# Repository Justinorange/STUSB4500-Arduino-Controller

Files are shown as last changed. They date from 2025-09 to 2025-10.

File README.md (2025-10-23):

# STUSB4500 USB-C Power Delivery (PD) Sink Controller

A custom **KiCAD project** for building a **USB Power Delivery (USB-PD) Sink Board** utilizing the STMicroelectronics **STUSB4500** controller.

This board provides a powerful and flexible way to draw high-power **variable voltage** from any standard USB-C PD power source. It is designed to be fully controllable by an external host microcontroller, via the **I²C bus**.

---

## Features

* **USB-PD Protocol Negotiation**: Automatically handles the USB-PD handshake process.
* **I²C Control**: Allows a host MCU (e.g., Arduino, ESP32) to digitally request specific voltages.
* **Configurable Voltages**: Supports requesting standard USB-PD voltages: **5V, 9V, 12V, 15V, or 20V**.
* **Compact Design**: Designed as a simple, custom PCB project in KiCAD.

---

## Hardware Overview

The board is designed around the dedicated **STUSB4500** chip, which simplifies the PD sink implementation significantly by handling the communication protocol stack internally.

| Component | Description |
| :--- | :--- |
| **Controller IC** | STUSB4500 USB-PD Sink Controller |
| **Input** | USB-C receptacle for PD power source input |
| **Host Interface** | 5-pin JST connector for I²C communication with the microcontroller |
| **Power Output** | 2-pin JST connector for regulated DC output power |

The full schematic and PCB layout files are available in the KiCAD project directory (`/kicad/`).

---

## I²C Connection Pinout

This pinout is designed for compatibility with the ESP32 Arduino Nano, using a standard **5-pin JST header**.

| STUSB4500 Board Pin | Signal | Arduino (e.g., Nano/Uno) | Function |
| :--- | :--- | :--- | :--- |
| **SDA** | I²C Data | A4 | I²C Serial Data Line |
| **SCL** | I²C Clock | A5 | I²C Serial Clock Line |
| **RST** | Reset | D0 | External Reset Pin for STUSB4500 |
| **VDD** | Power Input | Vin (20V) | Power Supply for Arduino/STUSB4500 Logic |
| **GND** | Ground | GND | Common Ground Reference |

---

## How to Use (Arduino Example)

Follow these steps to quickly test and control the power negotiation using an Arduino or compatible microcontroller.

### Prerequisites

* **Code**: You will need the specific library/code to communicate with the STUSB4500 over I²C.
* **Connection**: Ensure the board is wired correctly according to the table above.
* **Power**: Connect a **USB-C PD power source** (charger) to the board's USB-C input.

### Negotiation Workflow

1.  **Upload**: Upload the I²C configuration code to your Arduino.
2.  **Monitor**: Open the **Serial Monitor** at 9600 baud.
3.  **Input**: Enter the desired target voltage (**5, 9, 12, 15, or 20**) and press Enter.
4.  **Negotiation**: The Arduino code will:
    * Configure the STUSB4500's I²C registers with the requested voltage.
    * The **STUSB4500 chip** will initiate a negotiation request to the power source.
5.  **Status**: The negotiated status (Success or Failure) and the resulting stable output voltage will be printed back to the Serial Monitor.
6.  **Output**: The requested voltage will be delivered to the **2-pin JST output terminal**.

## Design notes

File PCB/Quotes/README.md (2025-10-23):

# Pricing and Sourcing

---

## Lowest PCB Price

The lowest price for **PCB fabrication** was provided by **OSH Park**.

* *Note:* A potential way to get a lower price is by ordering from a manufacturer in China.

---

## Bill of Materials (BOM)

A complete **Bill of Materials (BOM)** is available, detailing all necessary components and their prices.

* All components can be sourced from **Digi-Key**.
* **[View the Bill of Materials (BOM)](BOM-STUSB.xlsx)**

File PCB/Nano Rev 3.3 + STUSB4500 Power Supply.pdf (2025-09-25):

# Nano Rev 3.3 + STUSB4500 Power Supply

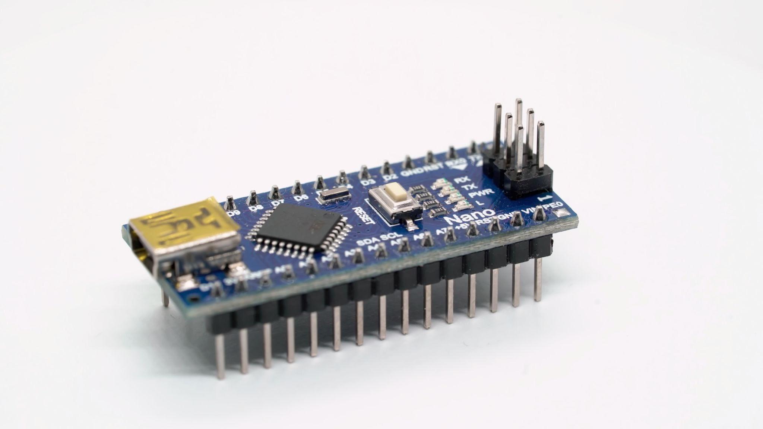
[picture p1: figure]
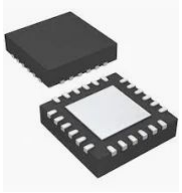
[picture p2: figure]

# USB Interface

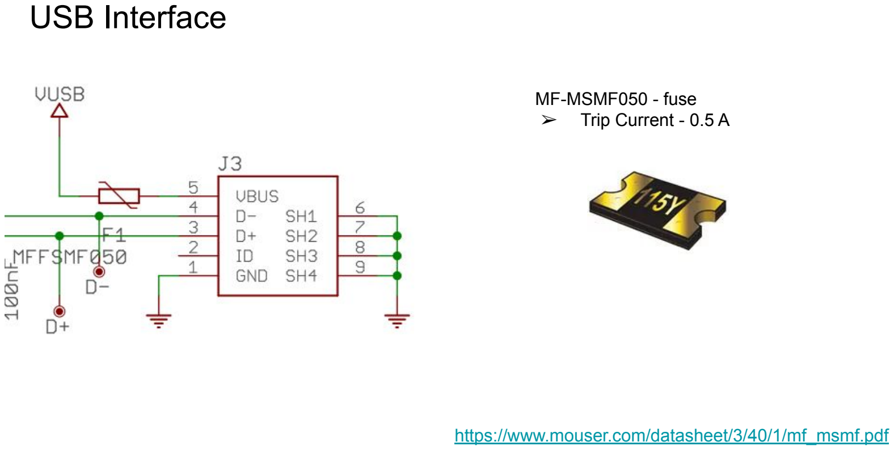
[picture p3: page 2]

MF-MSMF050 - fuse
- Trip Current - 0.5 A

https://www.mouser.com/datasheet/3/40/1/mf_msmf.pdf

# VUSB to 5V

SS1P3L - Diode
- Reverse Amps - 200 μA

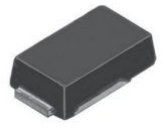
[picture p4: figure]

Reverse Peak Voltage - 30 V

https://www.vishay.com/docs/88915/ss1p3l.pdf

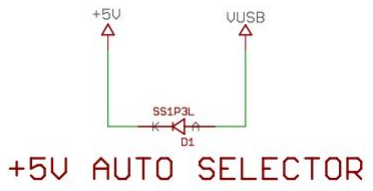
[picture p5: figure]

# VIN to 5V

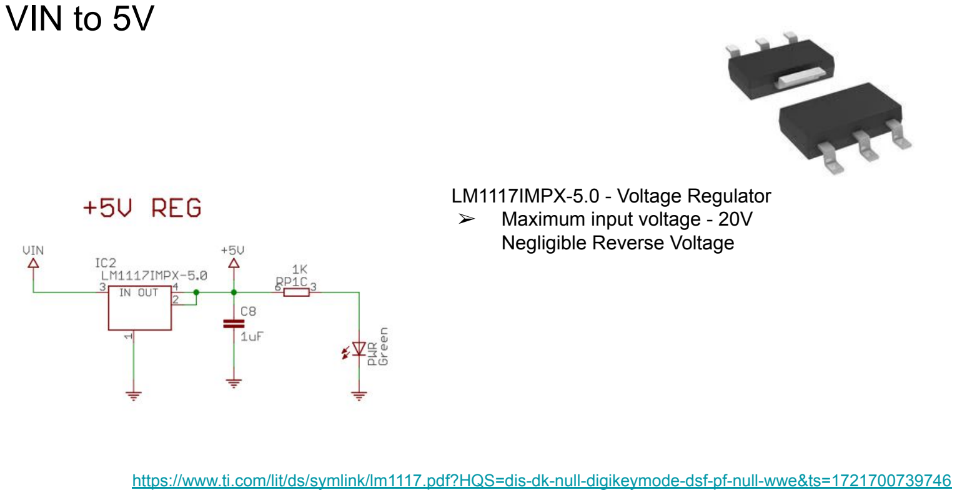
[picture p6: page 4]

LM1117IMPX-5.0 - Voltage Regulator
- Maximum input voltage - 20V Negligible Reverse Voltage

https://www.ti.com/lit/ds/symlink/lm1117.pdf?HQS=dis-dk-null-digikeymode-dsf-pf-null-wwe&ts=1721700739746

# 5V to Arduino IC

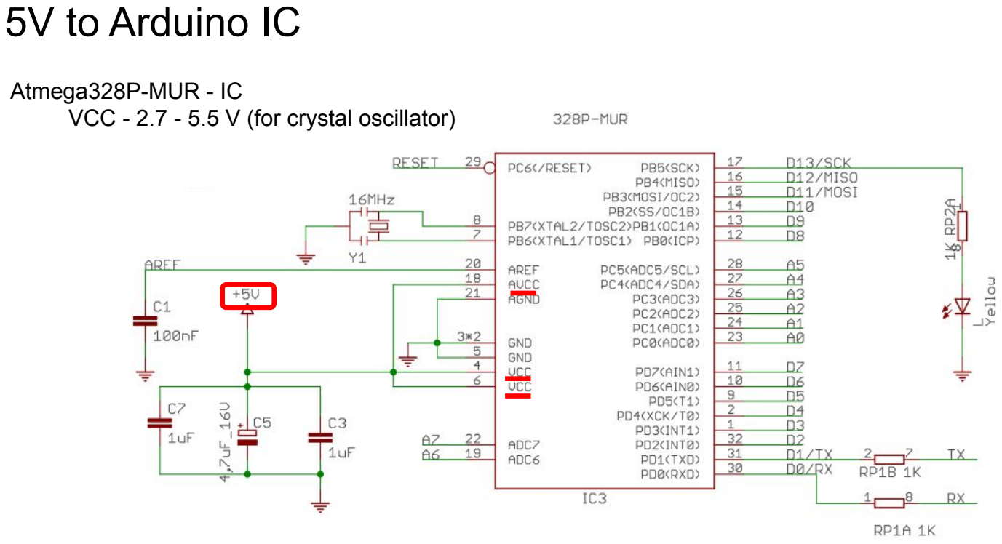
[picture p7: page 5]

Atmega328P-MUR - IC
VCC - 2.7 - 5.5 V (for crystal oscillator)

# 3V3 & FT23RL

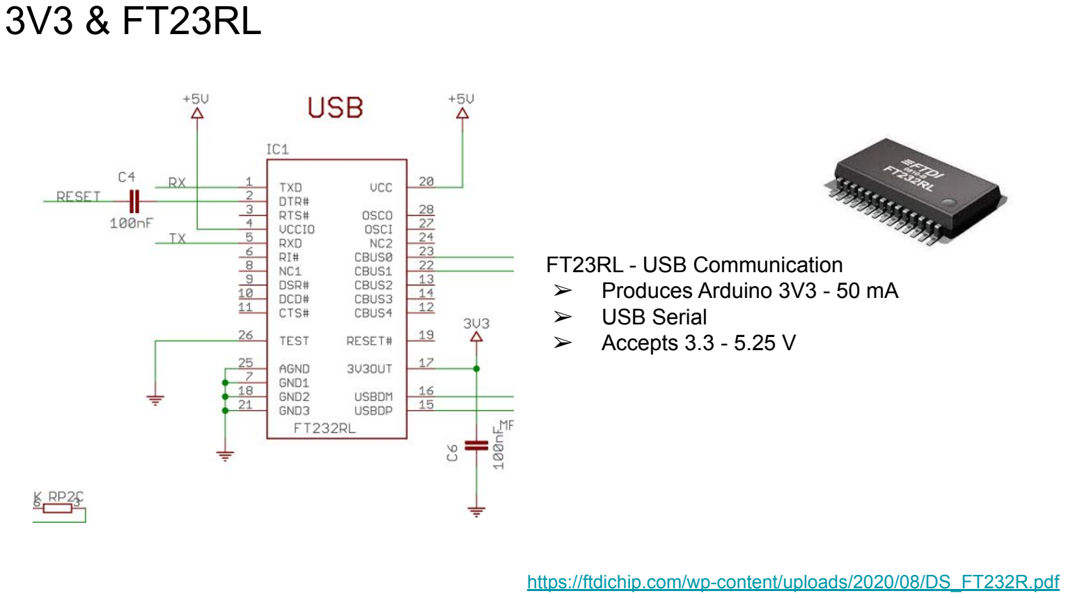
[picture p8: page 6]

FT23RL - USB Communication
- Produces Arduino 3V3 - 50 mA
- USB Serial
- Accepts 3.3 - 5.25 V

https://ftdichip.com/wp-content/uploads/2020/08/DS_FT232R.pdf

# Power Movement

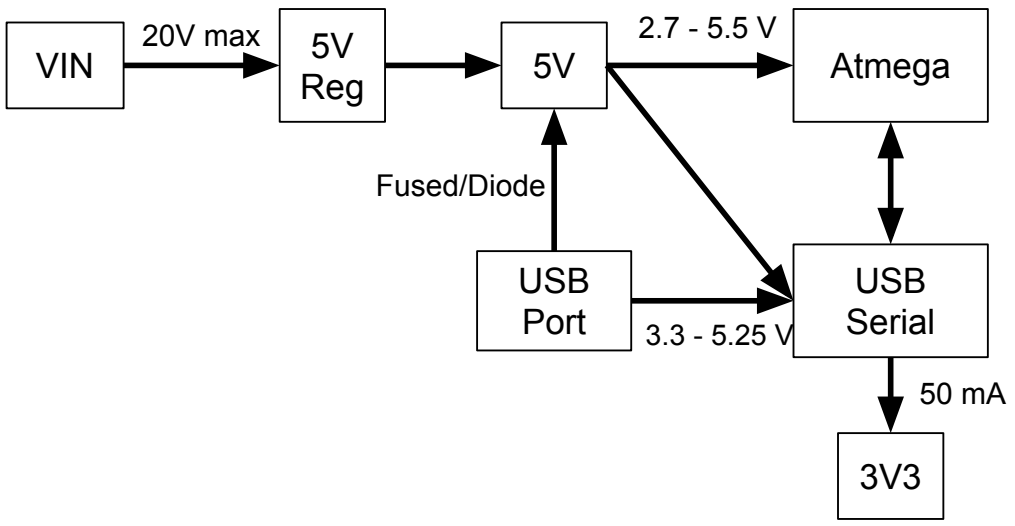
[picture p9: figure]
VIN; Reg; Atmega; USB Serial; USB Port; 20V max; Fused/Diode

# Schematic

## https://docs.arduino.cc/resources/schematics/A000005-schematics.pdf

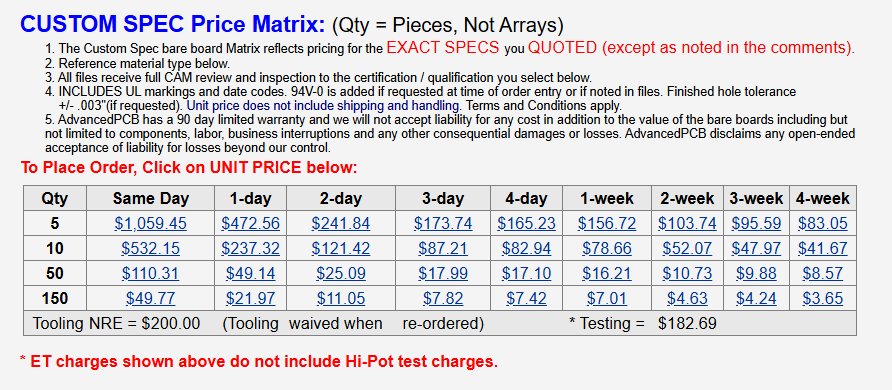
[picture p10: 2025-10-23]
PCB/Quotes/AdvancedPCB.png

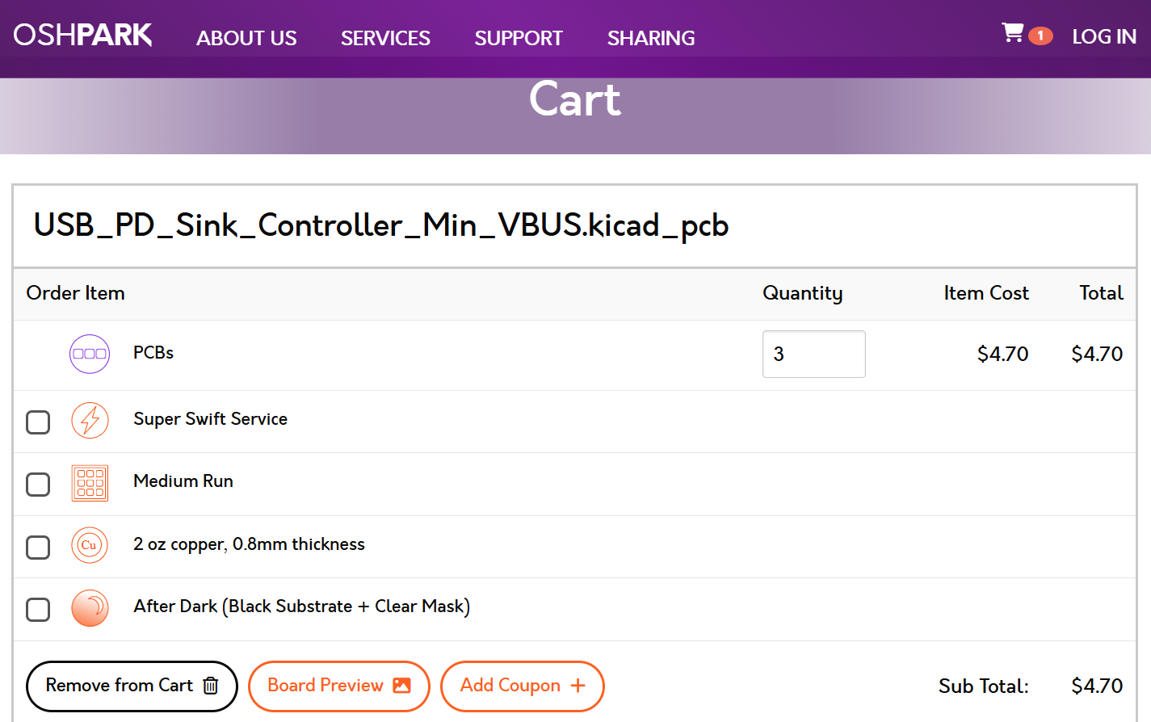
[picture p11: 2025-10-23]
PCB/Quotes/OSHPark.png

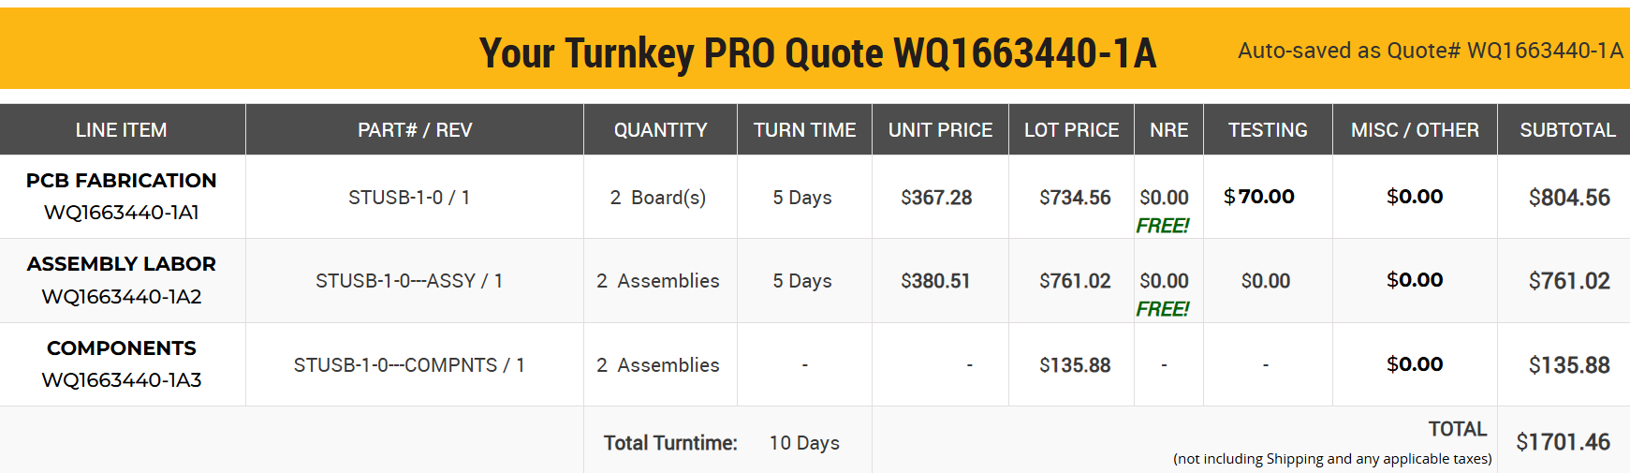
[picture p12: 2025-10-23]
PCB/Quotes/SierraQuote.png

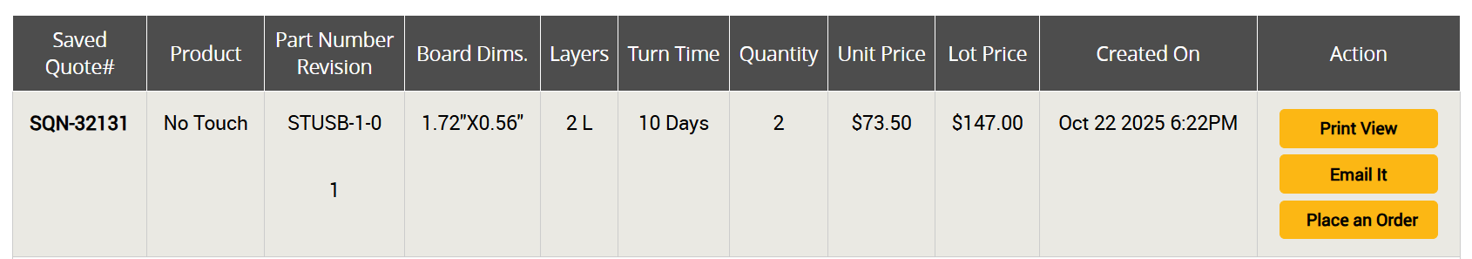
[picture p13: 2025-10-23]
PCB/Quotes/CheaperSierraCircuits.png

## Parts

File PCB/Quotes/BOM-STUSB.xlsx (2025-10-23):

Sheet: Sierra Sample BOM
BOM: STUSB-1-0
Assembly Part Number/Revision: 1
Item # | Quantity per board | Manufacturer Part # | Unit Price | Reference designators | Value (optional) | Total Price
2 | 1 | TMK107BBJ475KA-T | $0.28 | C1 | 4.7 μF | $0.28
3 | 4 | UMK107BJ105KA-T | $0.08 | C2,C3,C4,C5 | 1μF | $0.32
4 | 1 | TMK107BJ104KA-T | $0.08 | C6 | 100nF | $0.08
5 | 2 | ESDA25P35-1U1M | $0.37 | D1,D4 | ESDA25P35-1U1M | $0.74
6 | 1 | ESDA25W | $0.42 | D2 | ESDA25W | $0.42
7 | 2 | CD0603-B0240R | $0.21 | D3,D5 | Diode | $0.42
8 | 1 | USB4105-GF-A | $0.78 | J1 | USB_C_Receptacle_PowerOnly_6P | $0.78
9 | 1 | S2B-XH-A | $0.12 | J2 | JST_01x02_Socket | $0.12
10 | 1 | S5B-XH-A | $0.22 | J3 | JST_01x05_Socket | $0.22
11 | 1 | RC0603JR-07470RL | $0.10 | R1 | 470R | $0.10
12 | 2 | RT0603FRE071KL | $0.10 | R2,R6 | 1kR | $0.20
13 | 1 | RT0603DRE0722KL | $0.10 | R3 | 22kR | $0.10
14 | 1 | RC0603FR-07100KL | $0.10 | R4 | 100kR | $0.10
15 | 1 | RT0603DRE07100RL | $0.10 | R5 | 100R | $0.10
16 | 1 | CRCW080510K0FKEA | $0.10 | R7 | 10kR | $0.10
17 | 2 | RC0603JR-074K7L | $0.10 | R8,R10 | 4.7kR | $0.20
18 | 1 | STUSB4500QTR | $1.96 | U1 | STUSB4500QTR | $1.96
19 | 2 | STL6P3LLH6 | $1.54 | U2,U3 | STL6P3LLH6 | $3.08
Total | $9.32
END OF BOM

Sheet: USB_PD_Sink_Controller_Min_VBUS
Reference | Qty | Value | DNP | Exclude from BOM | Exclude from Board | Footprint | Datasheet
A1 | 1 | Arduino_Nano_ESP32 |  |  |  | Module:Arduino_Nano | https://docs.arduino.cc/resources/datasheets/ABX00083-datasheet.pdf
C1 | 1 | 4.7 μF |  |  |  | Capacitor_SMD:C_0603_1608Metric_Pad1.08x0.95mm_HandSolder | ~
C2,C3,C4,C5 | 4 | 1μF |  |  |  | Capacitor_SMD:C_0603_1608Metric_Pad1.08x0.95mm_HandSolder | ~
C6 | 1 | 100nF |  |  |  | Capacitor_SMD:C_0603_1608Metric_Pad1.08x0.95mm_HandSolder | ~
D1,D4 | 2 | ESDA25P35-1U1M |  |  |  | ST_1610:ST_1610 | kicad-embed://esda25p35-1u1m.pdf
D2 | 1 | ESDA25W |  |  |  | ST_SOT323-3L:ST_SOT323-3L
D3,D5 | 2 | D |  |  |  | Diode_SMD:D_0603_1608Metric_Pad1.05x0.95mm_HandSolder | ~
J1 | 1 | USB_C_Receptacle_PowerOnly_6P |  |  |  | Connector_USB:USB_C_Receptacle_GCT_USB4105-xx-A_16P_TopMnt_Horizontal | https://www.usb.org/sites/default/files/documents/usb_type-c.zip
J2 | 1 | JST_01x02_Socket |  |  |  | Connector_JST:JST_XH_S2B-XH-A_1x02_P2.50mm_Horizontal | ~
J3 | 1 | JST_01x05_Socket |  |  |  | Connector_JST:JST_XH_S5B-XH-A_1x05_P2.50mm_Horizontal | ~
R1 | 1 | 470R |  |  |  | Resistor_SMD:R_0603_1608Metric_Pad0.98x0.95mm_HandSolder | ~
R2,R6 | 2 | 1kR |  |  |  | Resistor_SMD:R_0603_1608Metric_Pad0.98x0.95mm_HandSolder | ~
R3 | 1 | 22kR |  |  |  | Resistor_SMD:R_0603_1608Metric_Pad0.98x0.95mm_HandSolder | ~
R4 | 1 | 100kR |  |  |  | Resistor_SMD:R_0603_1608Metric_Pad0.98x0.95mm_HandSolder | ~
R5 | 1 | 100R |  |  |  | Resistor_SMD:R_0603_1608Metric_Pad0.98x0.95mm_HandSolder | ~
R7 | 1 | 10kR |  |  |  | Resistor_SMD:R_0603_1608Metric_Pad0.98x0.95mm_HandSolder | ~
R8,R10 | 2 | 4.7kR |  |  |  | Resistor_SMD:R_0603_1608Metric_Pad0.98x0.95mm_HandSolder | ~
U1 | 1 | STUSB4500QTR |  |  |  | Package_DFN_QFN:QFN-24-1EP_4x4mm_P0.5mm_EP2.7x2.7mm | https://www.st.com/resource/en/datasheet/stusb4500.pdf
U2,U3 | 2 | STL6P3LLH6 |  |  |  | STL6P3LLH6:POWERFLAT_3P3X3P3_STM2 | https://www.st.com/resource/en/datasheet/stl6p3llh6.pdf

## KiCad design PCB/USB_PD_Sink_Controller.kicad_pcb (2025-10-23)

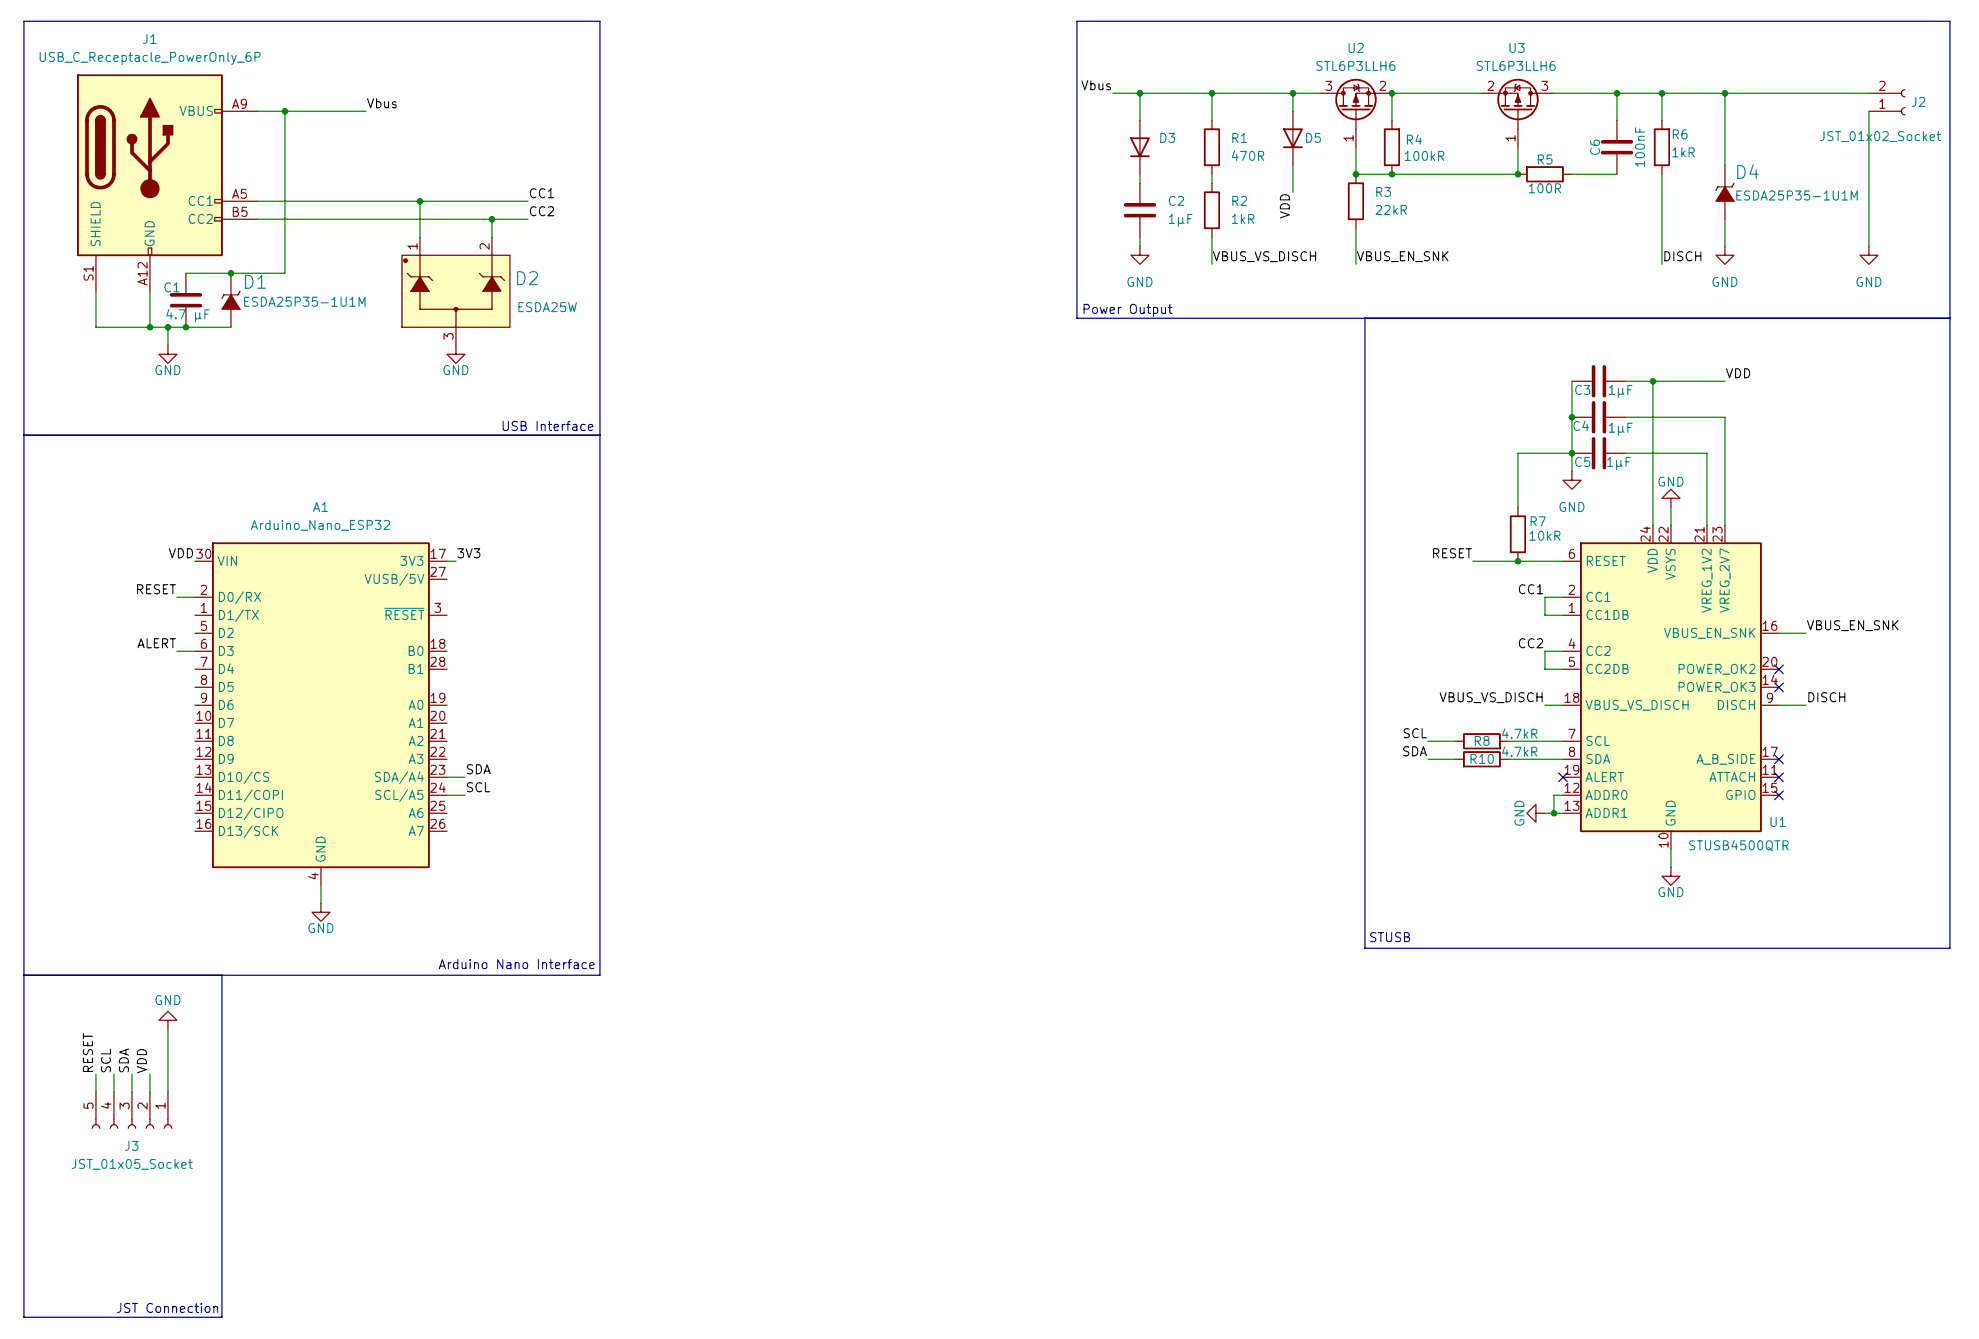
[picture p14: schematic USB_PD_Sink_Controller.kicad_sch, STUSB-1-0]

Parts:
A1: Arduino_Nano_ESP32; Arduino_Nano
C1: 4.7 μF; C_0603_1608Metric_Pad1.08x0.95mm_HandSolder
C2, C3, C4, C5: 1μF; C_0603_1608Metric_Pad1.08x0.95mm_HandSolder
C6: 100nF; C_0603_1608Metric_Pad1.08x0.95mm_HandSolder
D1, D4: ESDA25P35-1U1M; ST_1610
D2: ESDA25W; ST_SOT323-3L
D3, D5: D; D_0603_1608Metric_Pad1.05x0.95mm_HandSolder
J1: USB_C_Receptacle_PowerOnly_6P; USB_C_Receptacle_GCT_USB4105-xx-A_16P_TopMnt_Horizontal
J2: JST_01x02_Socket; JST_XH_S2B-XH-A_1x02_P2.50mm_Horizontal
J3: JST_01x05_Socket; JST_XH_S5B-XH-A_1x05_P2.50mm_Horizontal
R1: 470R; R_0603_1608Metric_Pad0.98x0.95mm_HandSolder
R2, R6: 1kR; R_0603_1608Metric_Pad0.98x0.95mm_HandSolder
R3: 22kR; R_0603_1608Metric_Pad0.98x0.95mm_HandSolder
R4: 100kR; R_0603_1608Metric_Pad0.98x0.95mm_HandSolder
R5: 100R; R_0603_1608Metric_Pad0.98x0.95mm_HandSolder
R7: 10kR; R_0603_1608Metric_Pad0.98x0.95mm_HandSolder
R8, R10: 4.7kR; R_0603_1608Metric_Pad0.98x0.95mm_HandSolder
U1: STUSB4500QTR; QFN-24-1EP_4x4mm_P0.5mm_EP2.7x2.7mm
U2, U3: STL6P3LLH6; POWERFLAT_3P3X3P3_STM2

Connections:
/CC1: D2.1, J1.A5 (CC1), U1.1 (CC1DB), U1.2 (CC1)
/CC2: D2.2, J1.B5 (CC2), U1.4 (CC2), U1.5 (CC2DB)
/DISCH: R6.1, U1.9 (DISCH)
/RESET: A1.2 (D0/RX), J3.5, R7.2, U1.6 (RESET)
/SCL: A1.24 (SCL/A5), J3.4, R8.1
/SDA: A1.23 (SDA/A4), J3.3, R10.2
/VBUS_EN_SNK: R3.2, U1.16 (VBUS_EN_SNK)
/VBUS_VS_DISCH: R2.2, U1.18 (VBUS_VS_DISCH)
/VDD: A1.30 (VIN), C3.1, D5.1 (K), J3.2, U1.24 (VDD)
/Vbus: C1.1, D1.1 (K), D3.2 (A), D5.2 (A), J1.A9 (VBUS), J1.B9 (VBUS), R1.1, U2.3 (D)
GND: A1.4 (GND), A1.29 (GND), C1.2, C2.2, C3.2, C4.2, C5.2, D1.2 (A), D2.3, D4.2 (A), J1.A12 (GND), J1.B12 (GND), J1.S1 (SHIELD), J2.1, J3.1, R7.1, U1.10 (GND), U1.12 (ADDR0), U1.13 (ADDR1), U1.22 (VSYS), U1.25 (GND)
unnamed: C6.1, R5.1
unnamed: C2.1, D3.1 (K)
unnamed: C6.2, D4.1 (K), J2.2, R6.2, U3.3 (D)
unnamed: R1.2, R2.1
unnamed: R8.2, U1.7 (SCL)
unnamed: R10.1, U1.8 (SDA)
unnamed: C5.1, U1.21 (VREG_1V2)
unnamed: C4.1, U1.23 (VREG_2V7)
unnamed: R3.1, R4.1, R5.2, U2.1 (G), U3.1 (G)
unnamed: R4.2, U2.2 (S), U3.2 (S)

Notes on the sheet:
STUSB
Arduino Nano Interface
JST Connection
USB Interface
Power Output

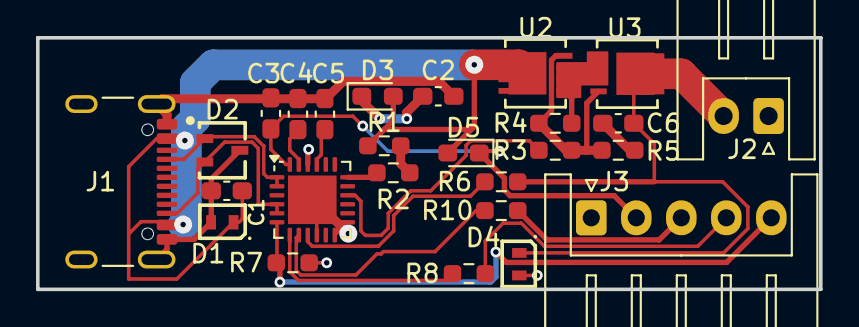
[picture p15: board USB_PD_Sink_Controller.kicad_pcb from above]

Board: 2 copper layers, 43.5 x 14.0 mm, 26 parts (0 on the bottom side), 21 nets.

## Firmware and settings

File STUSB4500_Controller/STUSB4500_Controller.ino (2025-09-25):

/*
  STUSB4500 USB PD Voltage Controller for Arduino Nano

  This sketch communicates with the STUSB4500 USB PD controller chip
  over I2C to change the negotiated power profile (voltage).

  Hardware Setup:
  - Arduino Nano
  - STUSB4500 Breakout Board
  - Arduino A4 (SDA) -> STUSB4500 SDA
  - Arduino A5 (SCL) -> STUSB4500 SCL
  - Arduino D2 -> STUSB4500 ALERT
  - Arduino GND -> STUSB4500 GND
  - Arduino 5V -> STUSB4500 VDD (if not powered from VBUS)
  - Ensure necessary pull-up resistors are in place for I2C lines and ALERT.

  How to Use:
  1. Upload this code to your Arduino Nano.
  2. Open the Serial Monitor (baud rate: 9600).
  3. Type one of the following commands and press Enter:
     - '5' to request 5V
     - '9' to request 9V
     - '12' to request 12V
     - '15' to request 15V
     - '20' to request 20V
  4. The STUSB4500 will then negotiate the requested voltage with the USB PD source.
  5. The ALERT pin will signal when a new negotiation is complete or if an event occurs.
*/

#include <Wire.h>

// I2C address of the STUSB4500. Default is 0x28.
// Can be 0x29, 0x2A, or 0x2B depending on ADDR0 and ADDR1 pins.
#define STUSB4500_ADDRESS 0x28

// STUSB4500 Register Addresses
#define PDO_NUM_REG 0x70
#define V_SNK_PDO2_REG 0x85
#define V_SNK_PDO3_REG 0x87

// Digital pin connected to the STUSB4500's ALERT pin
#define ALERT_PIN 2

// A volatile boolean flag to be used by the interrupt service routine
volatile bool alert_flag = false;

void setup() {
  // Initialize Serial communication at 9600 baud
  Serial.begin(9600);
  Serial.println("STUSB4500 Voltage Controller Initialized");
  Serial.println("Enter a voltage (5, 9, 12, 15, or 20) to request a new power profile.");

  // Initialize I2C communication
  Wire.begin();

  // Set the ALERT pin as an input with a pull-up resistor
  pinMode(ALERT_PIN, INPUT_PULLUP);
  // Attach an interrupt to the ALERT pin, to be triggered on a falling edge
  attachInterrupt(digitalPinToInterrupt(ALERT_PIN), handleAlert, FALLING);
  
  // Initial soft reset of the STUSB4500 NVM to load default settings
  // This helps ensure the chip is in a known state.
  // Note: For production use, you would pre-program the NVM.
  // This example dynamically changes PDOs in RAM.
  i2cWrite(0x25, 0x01); // Trigger NVM read
  delay(10); // Wait for NVM to load
}

void loop() {
  // Check if there is data available to read from the serial port
  if (Serial.available() > 0) {
    // Read the incoming integer
    int target_voltage = Serial.parseInt();

    // Process the command
    switch (target_voltage) {
      case 5:
        Serial.println("Requesting 5V...");
        setVoltage(5);
        break;
      case 9:
        Serial.println("Requesting 9V...");
        setVoltage(9);
        break;
      case 12:
        Serial.println("Requesting 12V...");
        setVoltage(12);
        break;
      case 15:
        Serial.println("Requesting 15V...");
        setVoltage(15);
        break;
      case 20:
        Serial.println("Requesting 20V...");
        setVoltage(20);
        break;
      default:
        Serial.println("Invalid voltage. Please enter 5, 9, 12, 15, or 20.");
        break;
    }
  }

  // If the alert flag was set by the ISR, print a message and reset it
  if (alert_flag) {
    // An alert can be for various reasons. We check the negotiated power data object (PDO)
    // to see if the voltage contract has changed.
    uint8_t pdo_index = i2cRead(RDO_REG_STATUS) & 0x0F; // Read Sink PDO number in use

    int new_voltage = 0;

    switch (pdo_index) {
      case 1: // PDO1 is always 5V
        new_voltage = 5;
        break;
      case 2: // PDO2
        {
          // Read the 10-bit value from the register
          uint16_t pdo2_val = i2cRead(V_SNK_PDO2_REG) | ((i2cRead(V_SNK_PDO2_REG + 1) & 0x03) << 8);
          // Convert to volts (value * 50mV)
          new_voltage = (int)((pdo2_val * 50L) / 1000L);
        }
        break;
      case 3: // PDO3
        {
          // Read the 10-bit value from the register
          uint16_t pdo3_val = i2cRead(V_SNK_PDO3_REG) | ((i2cRead(V_SNK_PDO3_REG + 1) & 0x03) << 8);
          // Convert to volts (value * 50mV)
          new_voltage = (int)((pdo3_val * 50L) / 1000L);
        }
        break;
    }

    if (new_voltage != 0 && new_voltage != currentNegotiatedVoltage) {
      currentNegotiatedVoltage = new_voltage;
      Serial.print("Negotiation successful. Voltage is now: ");
      Serial.print(currentNegotiatedVoltage);
      Serial.println("V");
    } else {
      Serial.println("Alert received from STUSB4500 (no voltage change or status update).");
    }

    alert_flag = false;
  }
}

// Function to set the desired voltage by configuring the PDO profiles.
// The STUSB4500 supports up to 3 Sink PDOs.
// PDO1 is fixed at 5V. We will configure PDO2 and PDO3 to get other voltages.
void setVoltage(int voltage) {
  uint16_t pdo2_voltage = 0;
  uint16_t pdo3_voltage = 0;
  uint8_t num_pdos = 1; // Default is one PDO (5V)

  // According to the datasheet, the voltage is programmed in 50mV steps.
  // So, value = voltage / 0.05
  uint16_t voltage_val = voltage / 0.05;

  if (voltage == 5) {
    // To request 5V, we just set the number of PDOs to 1.
    // The STUSB4500 will then only negotiate the default 5V PDO.
    num_pdos = 1;
  } else {
    // For other voltages, we will set them as PDO2 and make PDO3 a copy.
    // This makes the negotiation more robust.
    num_pdos = 3;
    pdo2_voltage = voltage_val;
    pdo3_voltage = voltage_val;
  }
  
  // Write the voltage for PDO2 (registers 0x85 and 0x86)
  i2cWrite(V_SNK_PDO2_REG, pdo2_voltage & 0xFF);
  i2cWrite(V_SNK_PDO2_REG + 1, (pdo2_voltage >> 8) & 0x03);

  // Write the voltage for PDO3 (registers 0x87 and 0x88)
  i2cWrite(V_SNK_PDO3_REG, pdo3_voltage & 0xFF);
  i2cWrite(V_SNK_PDO3_REG + 1, (pdo3_voltage >> 8) & 0x03);

  // Set the number of active PDOs
  // Bits 6-7 of register 0x70 control this.
  // 0b00 or 0b01 -> 1 PDO
  // 0b10 -> 2 PDOs
  // 0b11 -> 3 PDOs
  uint8_t pdo_num_val = 0;
  if (num_pdos == 1) pdo_num_val = 0b01;
  if (num_pdos == 2) pdo_num_val = 0b10;
  if (num_pdos == 3) pdo_num_val = 0b11;
  
  uint8_t current_pdo_reg = i2cRead(PDO_NUM_REG);
  current_pdo_reg &= 0x3F; // Clear bits 6-7
  current_pdo_reg |= (pdo_num_val << 6);
  i2cWrite(PDO_NUM_REG, current_pdo_reg);
  
  // After changing PDOs, we need to trigger a new negotiation.
  // A soft reset is an effective way to do this.
  i2cWrite(0x25, 0x01); // Send soft reset command
  
  Serial.print("Configuration sent for ");
  Serial.print(voltage);
  Serial.println("V. Awaiting negotiation...");
}

// Interrupt Service Routine for the ALERT pin
void handleAlert() {
  alert_flag = true;
}

// Helper function to write a byte to an I2C device register
void i2cWrite(uint8_t reg, uint8_t data) {
  Wire.beginTransmission(STUSB4500_ADDRESS);
  Wire.write(reg);
  Wire.write(data);
  Wire.endTransmission();
}

// Helper function to read a byte from an I2C device register
uint8_t i2cRead(uint8_t reg) {
  Wire.beginTransmission(STUSB4500_ADDRESS);
  Wire.write(reg);
  Wire.endTransmission(false); // Send a restart message, keeping the connection active
  Wire.requestFrom(STUSB4500_ADDRESS, (uint8_t)1); // Request 1 byte from the specified register
  if (Wire.available()) {
    return Wire.read();
  }
  return 0;
}

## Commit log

2025-09-25 Added KiCAD Files
    [USB_PD_Sink_Controller.kicad_pcb, USB_PD_Sink_Controller.kicad_sch]
2025-09-25 Added Pullup resistors and alert pin
    [USB_PD_Sink_Controller.kicad_pcb, USB_PD_Sink_Controller.kicad_sch]
2025-09-25 Update STUSB4500_Controller.ino
    Changed code to add alert pin
2025-09-25 Added capacitor to linear voltage regulator
    [USB_PD_Sink_Controller.kicad_pcb, USB_PD_Sink_Controller.kicad_sch]
2025-09-25 Revamped the PCB design
    Made many of the traces thicker. Changed from a barrel jack to a JST connector. Made the schematic pretty. Made the Arduino Nano directly soldered onto the board. Etc.
    [USB_PD_Sink_Controller.kicad_pcb, USB_PD_Sink_Controller.kicad_sch]
2025-09-25 Update and rename USB_PD_Sink_Controller.kicad_pcb to PCB/USB_PD_Sink_Controller.kicad_pcb
    Moved File
    [USB_PD_Sink_Controller.kicad_pcb]
2025-09-25 moved PCB files
    [USB_PD_Sink_Controller.kicad_sch]
2025-09-25 Added Ground plane and started LDO addition to SCH
    [USB_PD_Sink_Controller.kicad_pcb, USB_PD_Sink_Controller.kicad_sch]
2025-09-25 Added Arduino power explanation slides
2025-10-02 Made the Arduino esp32 and added a diode to prevent reverse voltage
    [USB_PD_Sink_Controller.kicad_pcb, USB_PD_Sink_Controller.kicad_sch]
2025-10-02 changed to ESP32 Arduino
2025-10-15 Added JST to schem
    [USB_PD_Sink_Controller.kicad_sch]
2025-10-16 VDD input added
    [USB_PD_Sink_Controller.kicad_sch]
2025-10-16 Updated PCB
    [USB_PD_Sink_Controller.kicad_pcb, USB_PD_Sink_Controller.kicad_sch]
2025-10-16 added Vbus variant
    [USB_PD_Sink_Controller_VBUS.kicad_pcb, USB_PD_Sink_Controller_VBUS.kicad_sch]
2025-10-16 added variant with less IO
    [USB_PD_Sink_Controller_Min_VBUS.kicad_pcb, USB_PD_Sink_Controller_Min_VBUS.kicad_sch]
2025-10-23 Made min VBUS main and added BOM
    [BOM-STUSB.xlsx, USB_PD_Sink_Controller.kicad_pcb, USB_PD_Sink_Controller.kicad_sch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]
2025-10-23 cleanup on some files and PCB
    [USB_PD_Sink_Controller.kicad_pcb]
2025-10-23 made small PCB change
    [USB_PD_Sink_Controller.kicad_sch]
